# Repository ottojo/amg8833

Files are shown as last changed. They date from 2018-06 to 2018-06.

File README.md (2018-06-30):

# AMG8833 Wemos D1 mini

This is a shield for the "Wemos D1 mini" ESP8266 board.
It contains a AMG8833 thermal sensor array, three WS2812 (Neopixel) LEDs and a 5V-logic-level output for interfacing additional RGB LEDs.

Top Side|Bottom Side
:-------------------------:|:-------------------------:
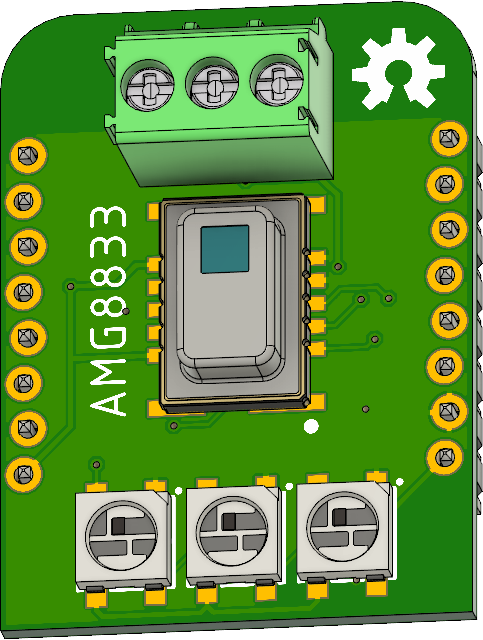
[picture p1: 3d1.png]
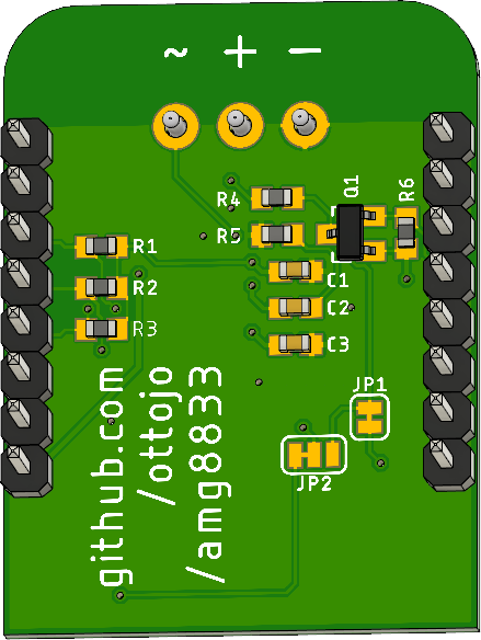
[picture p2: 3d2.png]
|
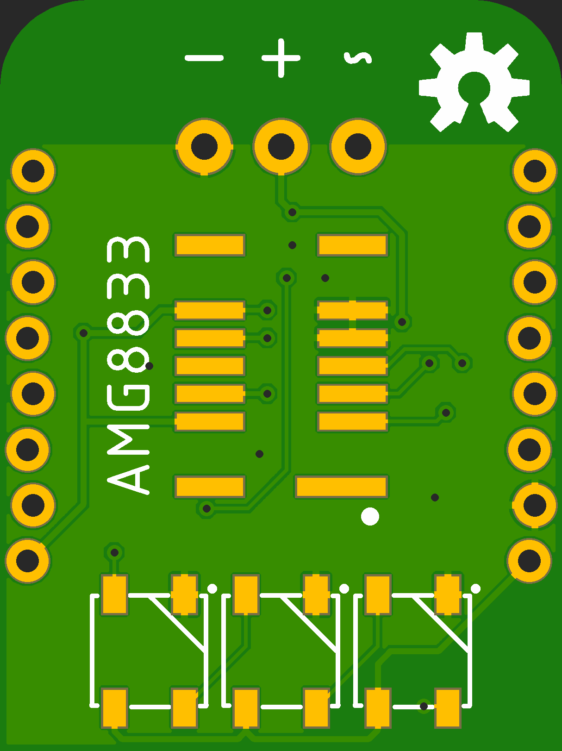
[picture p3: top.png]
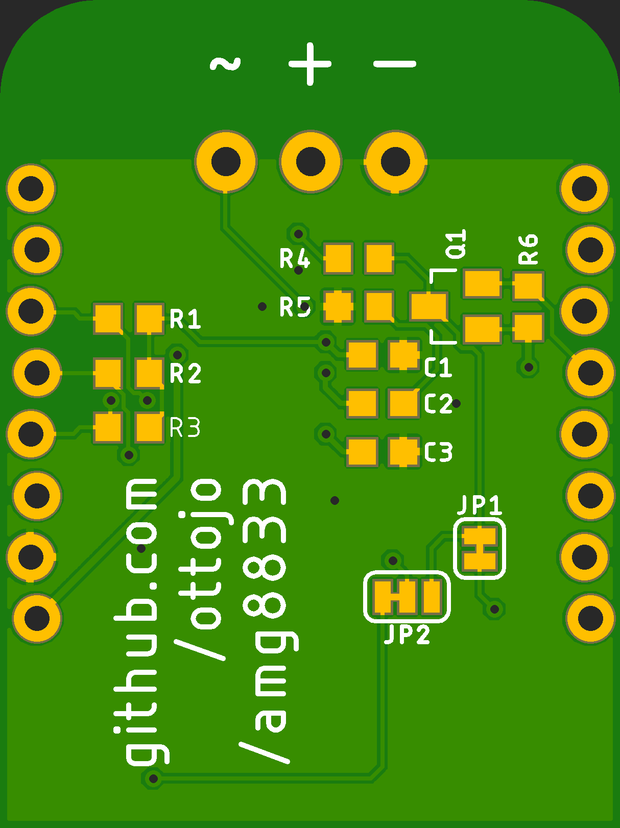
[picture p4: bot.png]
|

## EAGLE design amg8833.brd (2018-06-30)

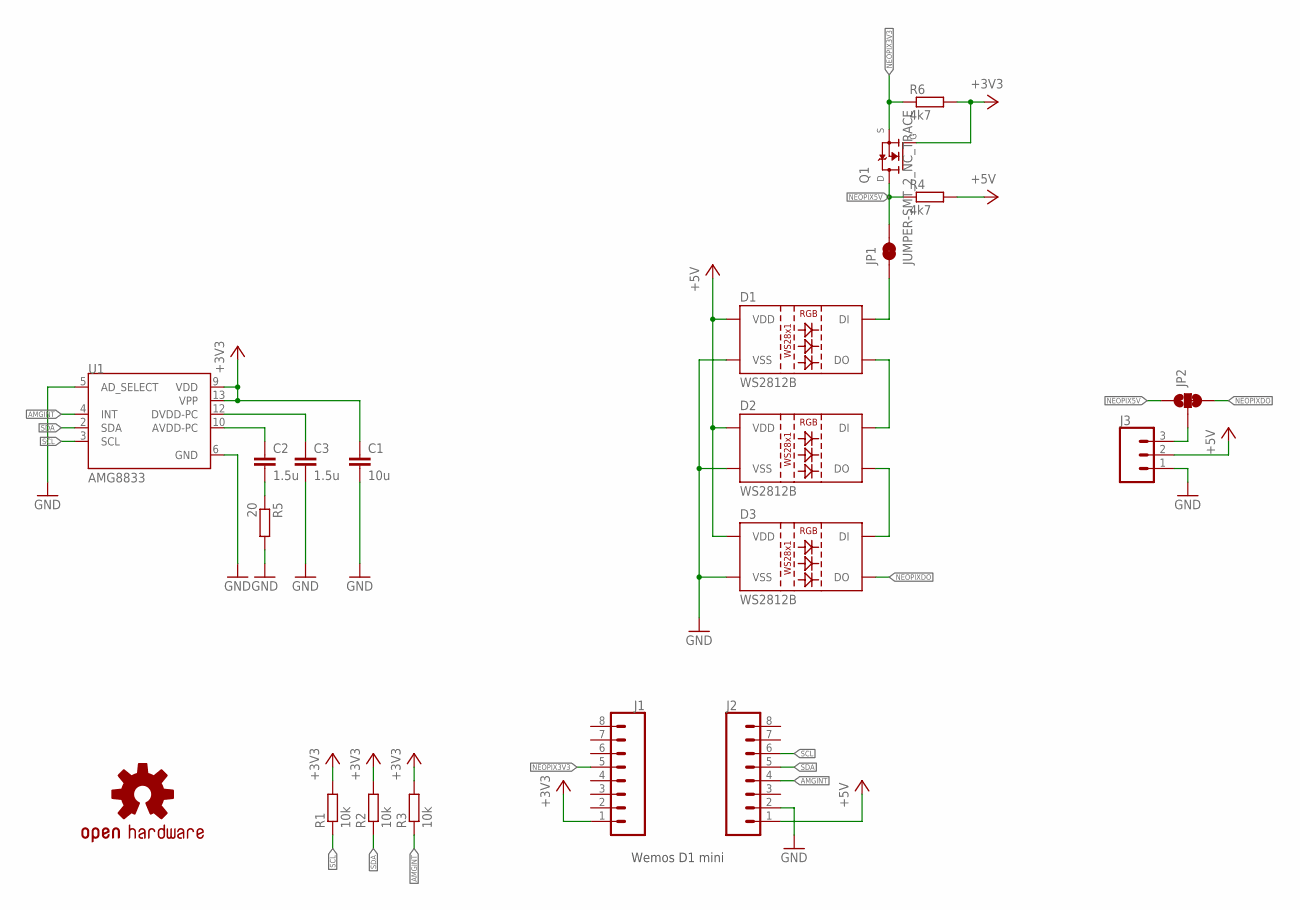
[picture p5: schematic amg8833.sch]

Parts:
C1: 10u; C0603
C2, C3: 1.5u; C0603
D1, D2, D3: WS2812B
J1, J2: CONN_08; 1X08_LOCK_NO_SILK
J3: CONN_03SCREWTERMINAL-3.5MM-3-NS; SCREWTERMINAL-3.5MM-3-NS
JP1: JUMPER-SMT_2_NC_TRACE; SMT-JUMPER_2_NC_TRACE_SILK
JP2: JUMPER-SMT_3_1-NC_TRACE; SMT-JUMPER_3_1-NC_TRACE_SILK
LOGO1: OSHW-LOGO; OSHW-LOGO-M
Q1: BSN20,215; BSN20_215
R1, R2, R3: 10k; R0603
R4, R6: 4k7; R0603
R5: 20; R0603
U1: AMG8833; XDCR_AMG8833

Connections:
+3V3: C1.1, J1.1, Q1.1 (G), R1.2, R2.2, R3.2, R6.2, U1.9 (VDD), U1.13 (VPP)
+5V: D1.1 (VDD), D2.1 (VDD), D3.1 (VDD), J2.1, J3.2, R4.2
AMGINT: J2.4, R3.1, U1.4 (INT)
GND: C1.2, C3.2, D1.3 (VSS), D2.3 (VSS), D3.3 (VSS), J2.2, J3.1, R5.2, U1.5 (AD_SELECT), U1.6 (GND)
MEOPIXOUT: J3.3, JP2.2
unnamed: C3.1, U1.12 (DVDD-PC)
unnamed: C2.1, U1.10 (AVDD-PC)
unnamed: D1.2 (DO), D2.4 (DI)
unnamed: D2.2 (DO), D3.4 (DI)
unnamed: D1.4 (DI), JP1.1
unnamed: C2.2, R5.1
NEOPIX3V3: J1.5, Q1.2 (S), R6.1
NEOPIX5V: JP1.2, JP2.1, Q1.3 (D), R4.1
NEOPIXDO: D3.2 (DO), JP2.3
SCL: J2.6, R1.1, U1.3 (SCL)
SDA: J2.5, R2.1, U1.2 (SDA)

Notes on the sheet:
Wemos D1 mini

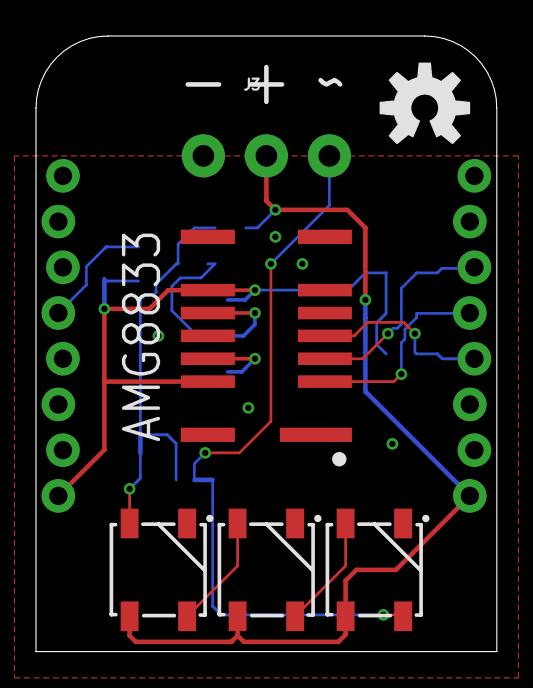
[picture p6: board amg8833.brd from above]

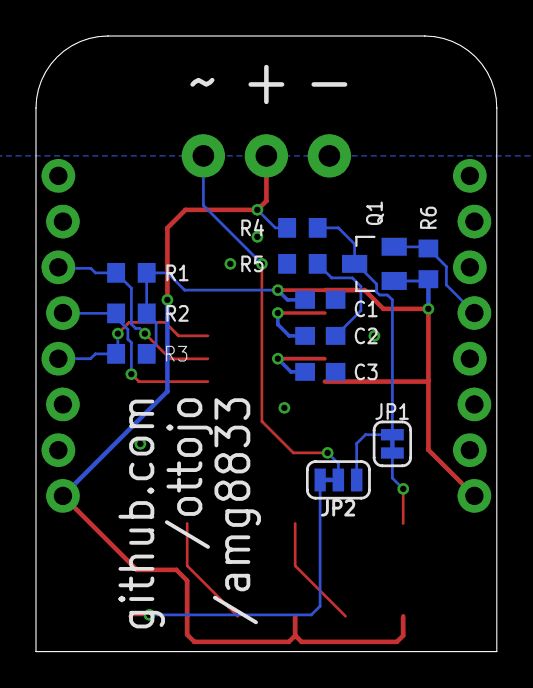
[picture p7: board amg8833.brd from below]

Board: 2 copper layers, 25.6 x 34.2 mm, 20 parts (12 on the bottom side), 16 nets.

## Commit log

2018-06-25 fixes #1, #2
    [amg8833.brd, amg8833.sch]
2018-06-25 silkscreen/naming fixes
    [amg8833.brd, amg8833.sch]
2018-06-25 fixed gnd path
    [amg8833.brd]
2018-06-25 fixed outline
    [amg8833.brd]
2018-06-30 3d stuff
    [amg8833.brd, amg8833.sch]
